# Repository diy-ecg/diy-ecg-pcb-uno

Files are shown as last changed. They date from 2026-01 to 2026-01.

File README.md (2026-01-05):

# diy-ecg-pcb-uno
 
# DIY ECG Amplifier Board (Arduino Uno Shield)

This repository contains the KiCad (v9) design files for a **DIY ECG (Electrocardiogram) amplifier board**.
The board is designed as an **Arduino Uno–compatible shield** and is intended for **educational, experimental, and research use**.

## Overview
- Analog front-end for ECG signal acquisition
- Designed for **Einthoven Lead I** measurements
- Uses a **MCP6004** quad operational amplifier
- Includes:
  - Differential ECG amplification
  - Biasing to a virtual ground (mid-supply)
  - Common-mode / body reference feedback (DRL-like concept)

The design is optimized for **low-cost components** and **didactic clarity**, making it suitable for
university courses, lab exercises, and DIY learning projects.

## Files
The repository intentionally contains only the essential KiCad files:
- `.kicad_sch` – schematic
- `.kicad_pcb` – PCB layout
- `.kicad_pro` – project file

These files are sufficient to inspect, modify, and manufacture the board.

## Intended Use
This board is **not a medical device** and must **not** be used for diagnostic or clinical purposes.
It is intended exclusively for:
- Education and teaching
- Private experimentation
- Research and prototyping

## License
This hardware design is licensed under the  
**CERN Open Hardware Licence Version 2 – Non-Commercial (CERN-OHL-NC v2)**.

You are free to study, modify, and manufacture the design for **private, educational, and research purposes**.
**Commercial use, sale, or mass production is not permitted** without explicit permission.

## Author
Jens Bongartz - info@diy-ecg.org

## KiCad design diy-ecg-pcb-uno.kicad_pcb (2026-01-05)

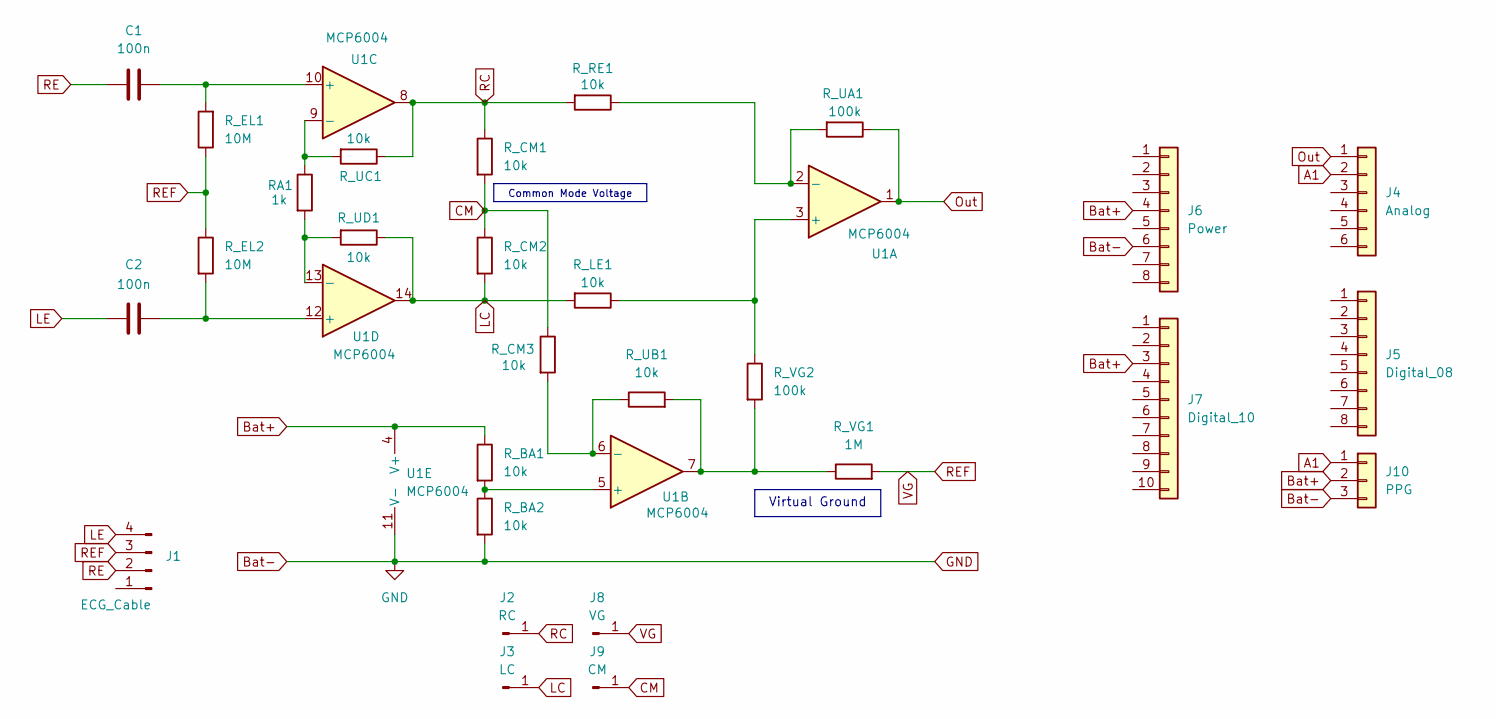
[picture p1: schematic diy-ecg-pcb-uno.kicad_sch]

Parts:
C1: 100n; C_Disc_D5.0mm_W2.5mm_P5.00mm
C2: 100n; C_Disc_D4.7mm_W2.5mm_P5.00mm
J1: ECG_Cable; PinHeader_1x04_P2.54mm_Vertical
J2: RC; PinHeader_1x01_P2.54mm_Vertical
J3: LC; PinHeader_1x01_P2.54mm_Vertical
J4: Analog; PinHeader_1x06_P2.54mm_Vertical
J5: Digital_08; PinHeader_1x08_P2.54mm_Vertical
J6: Power; PinHeader_1x08_P2.54mm_Vertical
J7: Digital_10; PinHeader_1x10_P2.54mm_Vertical
J8: VG; PinHeader_1x01_P2.54mm_Vertical
J9: CM; PinHeader_1x01_P2.54mm_Vertical
J10: PPG; PinHeader_1x03_P2.54mm_Horizontal
RA1: 1k; R_Axial_DIN0207_L6.3mm_D2.5mm_P10.16mm_Horizontal
R_BA1, R_BA2: 10k; R_Axial_DIN0207_L6.3mm_D2.5mm_P10.16mm_Horizontal
R_CM1, R_CM2, R_CM3: 10k; R_Axial_DIN0207_L6.3mm_D2.5mm_P10.16mm_Horizontal
R_EL1, R_EL2: 10M; R_Axial_DIN0207_L6.3mm_D2.5mm_P10.16mm_Horizontal
R_LE1: 10k; R_Axial_DIN0207_L6.3mm_D2.5mm_P10.16mm_Horizontal
R_RE1: 10k; R_Axial_DIN0207_L6.3mm_D2.5mm_P10.16mm_Horizontal
R_UA1: 100k; R_Axial_DIN0207_L6.3mm_D2.5mm_P10.16mm_Horizontal
R_UB1: 10k; R_Axial_DIN0207_L6.3mm_D2.5mm_P10.16mm_Horizontal
R_UC1: 10k; R_Axial_DIN0207_L6.3mm_D2.5mm_P10.16mm_Horizontal
R_UD1: 10k; R_Axial_DIN0207_L6.3mm_D2.5mm_P10.16mm_Horizontal
R_VG1: 1M; R_Axial_DIN0207_L6.3mm_D2.5mm_P10.16mm_Horizontal
R_VG2: 100k; R_Axial_DIN0207_L6.3mm_D2.5mm_P10.16mm_Horizontal
U1: MCP6004; DIP-14_W7.62mm_LongPads

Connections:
A1: J4.2 (A1), J10.1
Bat+: J6.4 (3V3), J7.3 (AREF), J10.2, R_BA1.1, U1.4 (V+)
Bat-: J6.6 (GND), J10.3, R_BA2.2, U1.11 (V-)
CM: J9.1, R_CM1.2, R_CM2.1, R_CM3.1
LC: J3.1, R_CM2.2, R_LE1.2, R_UD1.1, U1.14
LE: C2.2, J1.4
unnamed: R_UB1.2, R_VG1.1, R_VG2.2, U1.7
unnamed: R_LE1.1, R_VG2.1, U1.3 (+)
unnamed: R_RE1.1, R_UA1.2, U1.2 (-)
unnamed: R_BA1.2, R_BA2.1, U1.5 (+)
unnamed: R_CM3.2, R_UB1.1, U1.6 (-)
unnamed: C1.1, R_EL1.2, U1.10 (+)
unnamed: RA1.1, R_UC1.2, U1.9 (-)
unnamed: C2.1, R_EL2.2, U1.12 (+)
unnamed: RA1.2, R_UD1.2, U1.13 (-)
Out: J4.1 (A0), R_UA1.1, U1.1
RC: J2.1, R_CM1.1, R_RE1.2, R_UC1.1, U1.8
RE: C1.2, J1.2
REF: J1.3, J8.1, R_EL1.1, R_EL2.1, R_VG1.2

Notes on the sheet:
Common Mode Voltage
Virtual Ground

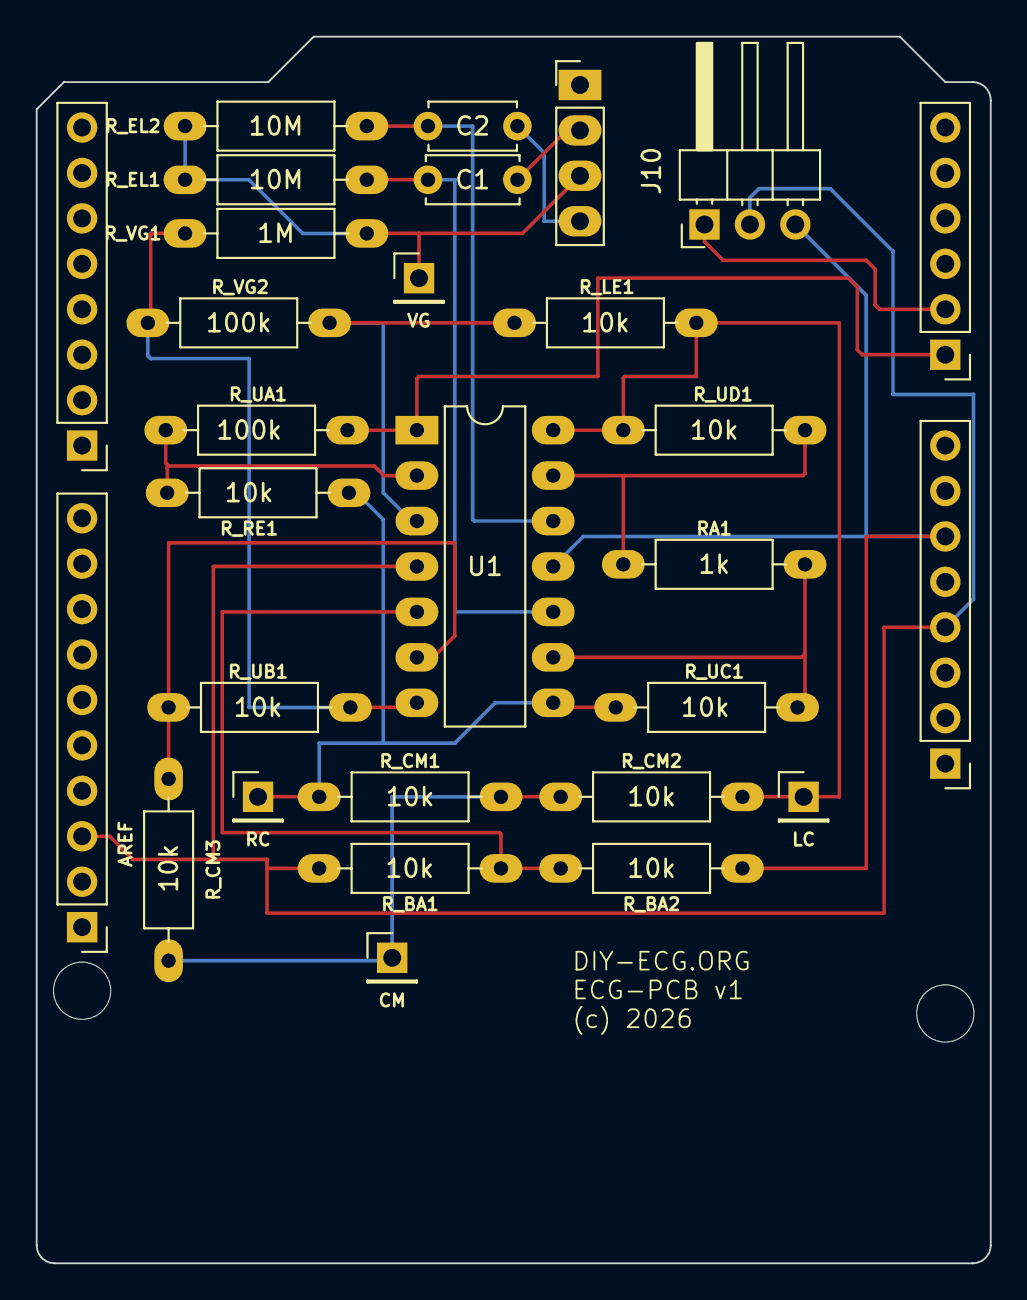
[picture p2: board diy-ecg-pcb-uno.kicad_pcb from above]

Board: 2 copper layers, 53.3 x 68.6 mm, 31 parts (0 on the bottom side), 19 nets.

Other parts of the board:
H2: MountingHole2; Arduino_MountingHole
H4: MountingHole4; Arduino_MountingHole

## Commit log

2026-01-05 Initial Project Upload
    [diy-ecg-pcb-uno.kicad_pcb, diy-ecg-pcb-uno.kicad_sch]
2026-01-05 I
    Updated README to specify KiCad version and removed commercial license note.
2026-10-14 Add readme for Cinch_Switch KiCAD files

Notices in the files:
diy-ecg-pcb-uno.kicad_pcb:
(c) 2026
